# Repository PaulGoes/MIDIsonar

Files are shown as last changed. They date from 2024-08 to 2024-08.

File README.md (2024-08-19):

# MIDIsonar
## An Arduino based MIDI Gesture Controller 
The MIDIsonar is a MIDI Gesture Controller based on an Arduino UNO with two HC-SR04 ultrasonic sensors.

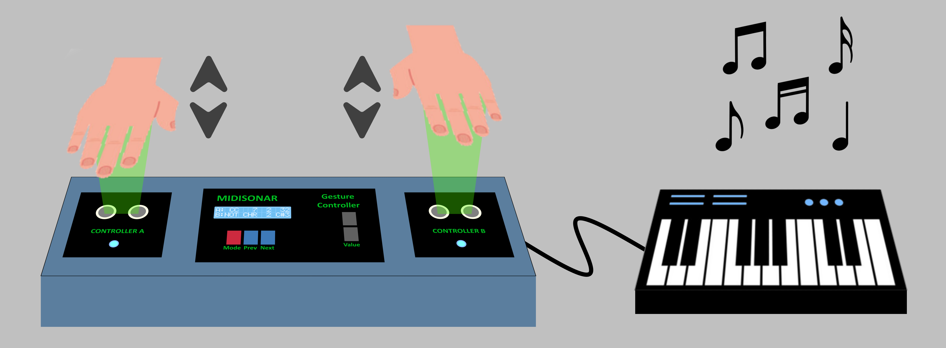
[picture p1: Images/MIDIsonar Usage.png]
MIDIsonar Welcome


With MIDIsonar you have ***two independent sonar based gesture controllers*** that let you create music by waving your hands up and down above the controllers.

Each gesture controller uses a ultrasonic sensor that measures the distance between itself and the hand above it using sonar waves (much like bats do to orientate themselves). 

By varying the distance between your hands and the ultrasonic sensors you ***generate musical information*** that can be send over the MIDI Out to any MIDI capable device like your synthesizer, drum machine or DAW.

<br/>

### MIDI information generated

MIDISonar lets you generate the following MIDI information:
- **MIDI Control Changes - Change the sound characteristics:**
    - Selectable MIDI CC number.
    - Selectable value range (min and max).
- **MIDI Notes - Play melodies and scales:**
    - Selectable root note.
    - Selectable scale (12 different available)
- **MIDI Chords - Play harmonies and progressions:**
    - Selectable root note.
    - Selectable chord progression (9 different available)
- **MIDI Pitchbend - Change the tone height of the sound:**
    - Selectable direction (up, down, up&down).
    - Selectable value range (min and max) and neutral zone .

<br/>

### Controller Configuration

For both controllers the following settings are available:
- **Active status:**
    - Set the controller active or not so you can use both or either one of the controllers.
- **Operational range:**
    - Set the range (minimum and maximum) in cm's in which the controller is operational (from 5cm to 80cm).
- **Polarity:**
    - Set the polarity of the controller, e.g. CC values increase or decrease when your hand is raised.
- **MIDI Channel:**
    - Set the MIDI channel of the controller so you can use both on the same or on different MIDI channels.

<br/>

### Musical usage examples

If set to two different MIDI channels the MIDIsonar can e.g. be used to:
- Play chord progressions with the left hand controlling a pad sound and play note melodies with the right hand controlling a lead sound.
- Control the filter of a running sequence sound with the left hand and play note melodies with the right hand controlling a lead sound.

If set to the same MIDI channel the MIDIsonar can e.g. be used to:
- Control the filter of a sound with the left hand and control the resonance of the same sound with the right hand.
- Control the volume of a sound with the left hand and control the pitch of the same sound to play the sound like a theremin.
- Trigger a single bass drum note with the left hand and trigger another single snare drum note with the right hand to play air drums.

<br/>

## Build it Yourself

You can build the MIDIsonar yourself. Just build it up like shown below and load the MIDIsonar.ino into the Arduino UNO. 

<br/>

### Schematic

Connect the various components as shown in this schematic diagram.

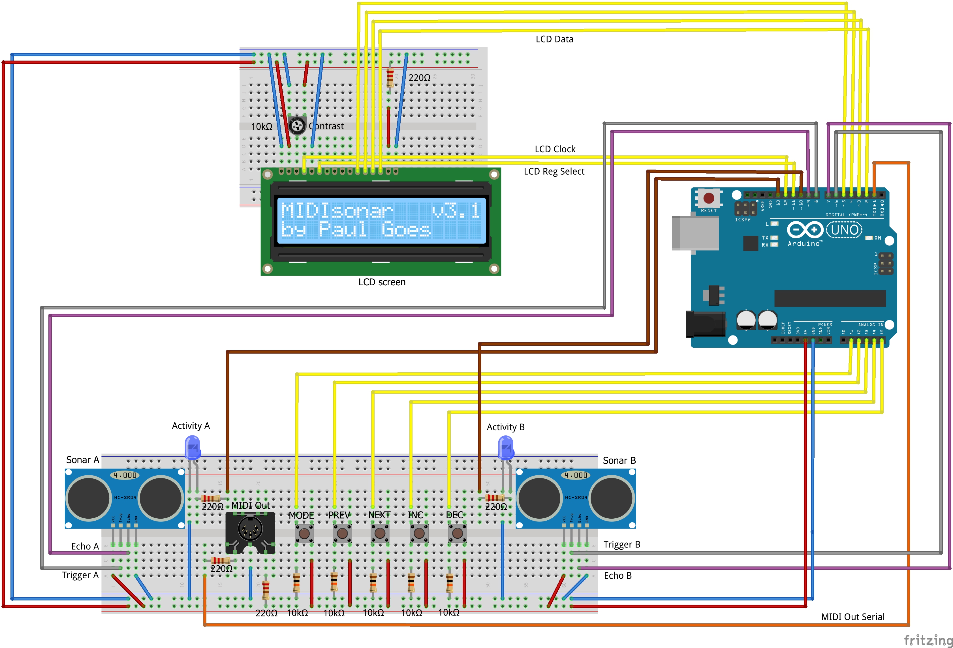
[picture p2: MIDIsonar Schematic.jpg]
MIDIsonar Schematic


<br/>

### Bill Of Materials

To build the MIDIsonar you need the following components.

| Component  | Quantity |
| --- | --- |
| Arduino UNO Microcontroller | 1x  |
| HC-RC04 ULtrasonic sensor  | 2x  |
| HD44780 16x2 LCD screen | 1x |
| MIDI Din Connector | 1x |
| Push buttons | 5x |
| LED diode | 2x |
| Potentiometer 10kOhm | 1x |
| Resistor 220Ohm | 5x |
| Resistor 10kOhm | 5x |
| Breadboard & Wires | 1x |

If you want to build a more permanent solution you might want to solder the components and you additionally need protyping PCB boards and soldering equipment.

If you want to build it into an enclosure you might additionally need wood, paint and screws (wooden enclosure or 3D printing equipment (3D printed plastic enclosure).

<br/>

### GPIO Pin definitions

The MIDIsonar defines the GPIO pins of the Arduino UNO as follows.

| GPIO | Usage | GPIO | Usage |
| --- | --- | --- | --- |
| TXD | Serial MIDI Out | D10 | Activity LED B |
| D2 | LCD Data bit 7 |  D11 | LCD Clock |
| D3 | LCD Data bit 6 | D12 | LCD Register Select |
| D4 | LCD Data bit 5 | D13 | Activity LED A |
| D5 | LCD Data bit 4 | A1 | Button MODE |
| D6 | Sensor B Trigger | A2 | Button PREV |
| D7 | Sensor B Echo | A3 | Button NEXT |
| D8 | Sensor A Trigger | A4 | Button INC |
| D9 | Sensor A Echo | A5 | Button DEC |

In the software the pins are defined at the beginning of the code. If you use another type of Arduino than an Arduino UNO, you might have to change the pin numbers to the corresponding ones for the type that you use.

<br/>

### Software

The software uses the following libraries:
- ``LiquidCrystal.h`` - to interface with the LCD screen
- ``NewPing.h`` - to interface with the ultrasonic sensors

The software consists of a ``setup()`` that initializes the MIDIsonar and displays the welcome message and a ``loop()`` that cycles through the three operational modes Standby, Setup and Play.

The software contains the following functions/subroutines:

- ``MODEstandby()`` - implements the Standby mode
- ``MODEsetup()`` - implements the Setup mode
- ``MODEplay()`` - implements the Play mode
- ``value2string()`` - converts values to strings for displaying purposes
- ``MIDIchord()`` - play chords by decomposing to individual notes
- ``MIDIpitchbend()`` - play pitchbend
- ``MIDImessage()`` - send individual MIDI message

The sketch uses 15010 bytes (46%) of program storage space. Global variables use 1894 bytes (92%) of dynamic memory.

<br/>

### Change the default controller setup

The MIDIsonar uses a default setup for the controllers. This default setup is loaded when the MIDIsonar is turned on. You can change this defaults if you want the MIDIsonar to start up with a different setup.

The default setup for the two controllers is defined at [line 137](https://github.com/PaulGoes/MIDIsonar/blob/b069583abb0d174fe831ef4dbfc4291921db8744/MIDIsonar.ino#L137) of the code.

```
/* initialize the data array with default values */
int value[2][18] = {
  { 1, 1, 1, 5, 50, 1, 7, 0, 127, 1, 60, 24, 1, 60, 14, 3, 3, 1 },	/* controller A: Active | CC 7 Volume over full range 0-127               */
  { 1, 2, 1, 5, 50, 1, 7, 0, 127, 1, 60, 24, 1, 60, 14, 3, 3, 1 }  	/* controller B: Active | NOTE Chromatic scale with root C3 with 24 steps */
```

The settings map to the following: 
| Controller| ACTV | TYPE | CHNL | LDST | HDST | POLR | CNTR | LVAL | HVAL | SCAL | ROOT | RANG | PROG | ROOT | RANG | TYPE | NTRL | PBFX |
| --- | --- | --- | --- | --- | --- | --- | --- | --- | --- | --- | --- | --- | --- | --- | --- | --- | --- | --- |
|  |  |  |  |  |  |  | CC | CC | CC | NOT | NOT | NOT | CHD | CHD | CHD | PB | PB | PB |
| A | 1 | 1 | 1 | 5 | 50 | 1 | 7 | 0 | 127 | 1 | 60 | 24 | 1 | 60 | 14 | 3 | 3 | 1 |
| B | 1 | 2 | 1 | 5 | 50 | 1 | 7 | 0 | 127 | 1 | 60 | 24 | 1 | 60 | 14 | 3 | 3 | 1 |

The defaults of both controllers are basically the same:

- Both send on MIDI channel 1 (CHNL) with a working range from 5 cm (LDST) to 50 cm (HDST).
- Controller A is set to TYPE 1 which means to send MIDI CC information. So it uses the config for the CC information: sending CC 7 (CC CNTR) over the full range of 0 (CC LVAL) to 127 (CC HVAL).
- Controller B is set to type 2 which means to send MIDI NOTE information. So it uses the config for the NOT information: using the chromatic scale (NOT SCAL) with root note C3 (NOT ROOT) and a range of 24 notes (NOT RANG).

The file [MIDIsonar datastructure pdf](https://github.com/PaulGoes/MIDIsonar/blob/master/MIDIsonar%20Datastructure.pdf) defines the settings and the values that can be used.

<br/>

### Change the controller sensitivity

The MIDIsonar's sensitivity can be changed in two different ways: configuring the ping medians and configuring the wiggle room.

The ping medians are defined at [line 149](https://github.com/PaulGoes/MIDIsonar/blob/b069583abb0d174fe831ef4dbfc4291921db8744/MIDIsonar.ino#L149) of the code.

```
/* initialize the data array with ping medians */
int pingmedian[4] = { 2, 3, 3, 2 };
```

The ultrasonic sensors work by sending a ping and measuring the time until they receive the echo. In order to prevent rogue measurements, it is possible to send multiple pings, discard the out-of-range measurements and calculate an average. The pingmedian array defines how many pings are used for each type of operation: MIDI CC (2), MIDI Notes (3), MIDI Chords (3), and MIDI Pitchbend (2).

> [!NOTE]
> Increasing the number of pings makes the measurements more reliable, but also makes the MIDIsonar react slower to the hand movements. So changing the ping medians is an act of balancing reliability vs performance.

The wiggle rooms are defined at [line 152](https://github.com/PaulGoes/MIDIsonar/blob/b069583abb0d174fe831ef4dbfc4291921db8744/MIDIsonar.ino#L152) of the code. 

```
/* initalize the data array with wiggle room */
int wiggleroom[4] = { 10, 10, 10, 0 };
```

The wiggle room is the minimum amount that a new measurement must differ from the previous measurement in order to be processed (in microseconds). This prevents that small movements of the hand or small imperfections in the measurements result in false triggerings. The wiggleroom array defines the wiggle rooms that are used for each type of operations: MIDI CC (10), MIDI Notes (10), MIDI Chords (10), and MIDI Pitchbend (0).

> [!NOTE]
> Increasing the wiggle room prevents false triggerings, but also makes the MIDIsonar react less well to small hand movements. So changing the wiggle room is an act of balancing accuracy vs coarseness.

<br/>

## Photo's

Here are some photo's of my MIDIsonar to give you inspiration to design you own enclosure.

MIDIsonar Photos

<br/>

## User Manual

When you power on the MIDIsonar it starts up with the welcome screen that displays the software version.

MIDIsonar Welcome

After a few seconds the MIDIsonar switches to the Standby Mode.

MIDIsonar Standby

<br/>

### Select Modes

By pressing the :red_square:**MODE** button you can cycle trought the three modes Standby, Setup and Play.

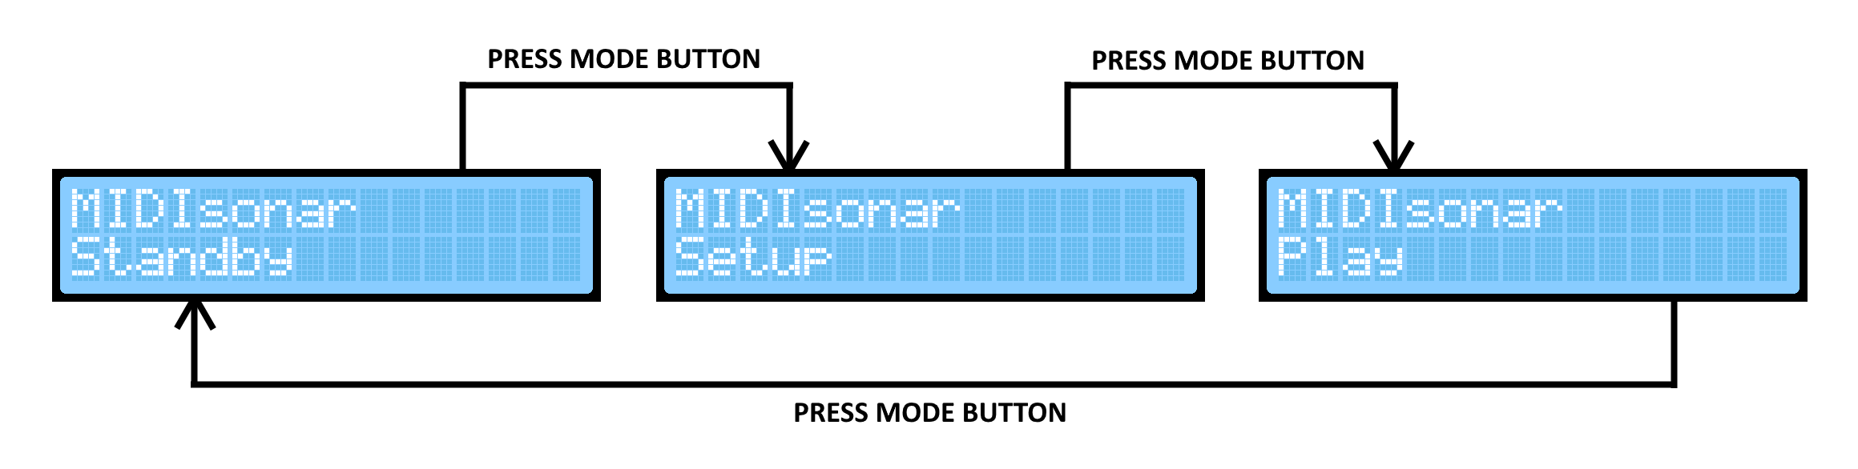
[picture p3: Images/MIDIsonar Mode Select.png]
MIDIsonar Mode Select


<br/>

### Play Mode

The MIDIsonar has a default setup and you can immediately use it by going to the Play mode. The default setup is:

MIDI controller A: 
- Active with a range from 5cm to 50cm, positive polarity.
- MIDI channel 1.
- Sending MIDI CC 7 (Volume) over the full range of 0 to 127.
  
MIDI controller B: 
- Active with a range from 5cm to 50cm, positive polarity.
- MIDI channel 1.
- Sending MIDI NOTES using a chromatic scale with root note C3 divided in 24 steps.

> [!NOTE]
> When in Play mode the activity LED's for controller A and controller B indicate whether the controller is active (lit) or not (dimmed).

When in Play mode the LCD screen gives visual feedback on the controls. For the default setup it shows the following information.

MIDIsonar Play Default

You can read from this screen that controller A is now sending CC 7 with a value 32 on MIDI channel 1 and controller B is now sending note G#3 also on MIDI channel 1.

<br/>

### Setup Mode

In Setup mode you can configure the settings for both controllers.

When you go into Setup Mode for the first time you are presented the first setup screen for controller A.

MIDIsonar Setup 1

The cursor (a thin line at the bottom) indicates which setting is currently selected. 

You can select different settings by pressing the :blue_square:**PREV** button (previous) and :blue_square:**NEXT** button (next). By pressing these buttons you cycle through the settings of controller A and controller B.

> [!NOTE]
> When you press the :blue_square:**NEXT** button at the last setting of controller B you will go to the first setting of controller A.<br/>
>
> When you press the :blue_square:**PREV** button at the first setting of controller A you will go to the last setting of controller B.

You can change the value of the selected setting by pressing the :black_large_square:**DEC** button (decrease) and :black_large_square:**INC** button (increase). 

> [!TIP]
> If you keep either :black_large_square:**DEC** or :black_large_square:**INC** button pressed it will scroll faster through the values.

> [!NOTE]
> When you return to Setup Mode after visiting Play mode you will return to the most recently edited setting.

<br/>

### Setup Screen organization

Each controller is configured by 9 settings arranged in 3 screens of 3 settings each. The third screen has settings that are dependent of the chosen type of operation on screen 1.

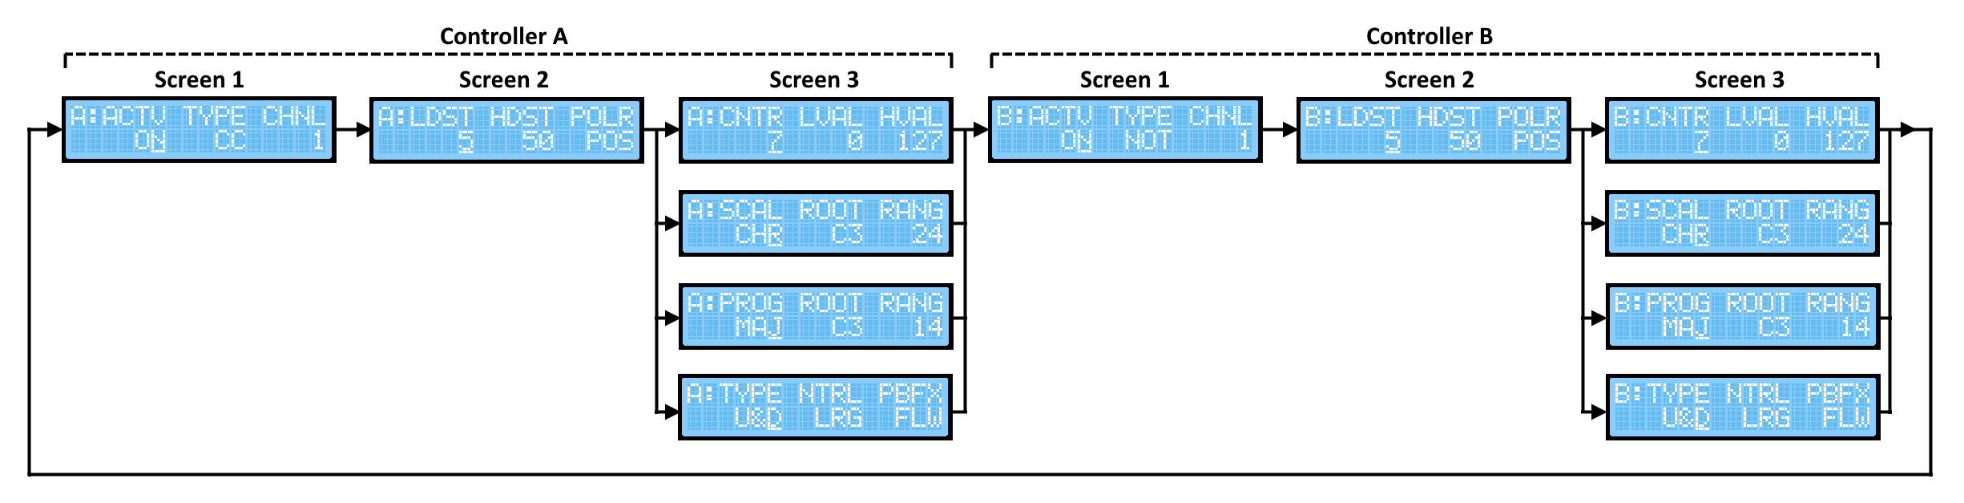
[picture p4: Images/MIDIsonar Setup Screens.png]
MIDIsonar Setup Organization


<br/>

### Settings of the first Setup screen

MIDIsonar Setup 1

- **ACTV:** Active
  - ON = Active
  - OFF = Inactive
- **TYPE:** Type of operation
  - CC = Send MIDI CC changes
  - NOT = Send MIDI Notes
  - CHD = Send MIDI Chords
  - PB = Send MIDI Pitchbend
- **CHNL:** MIDI Channel
  - 1-16 = MIDI Channel number

<br/>

### Settings of the second Setup screen

MIDIsonar Setup 2

- **LDST:** Low Distance
  - 5-80 = Low end of the operating range in cm (in steps of 5)
- **HDST:** High Distance
  - 5-80 = High end of the operating range in cm (in steps of 5)
- **POLR:** Polarity
  - POS = Positive mapping
  - NEG = Negative mapping
    
> [!NOTE]
> The HDST must be higher than the LDST. This is enforced when setting the values. 

The following image illustrates the effect of using positive and negative polarity.

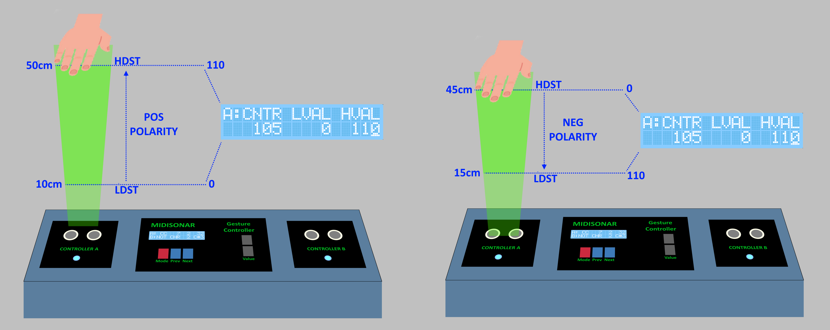
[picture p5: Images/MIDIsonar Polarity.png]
MIDIsonar Polarity


<br/>

### Settings of the third Setup screen - MIDI CC Changes

MIDIsonar Setup 3 CC

- **CNTR:** Controller number
  - 0-127 = MIDI CC number
- **LVAL:** Low Value
  - 0-127 = Lowest value generated
- **HVAL:** High Value
  - 0-127 = Highest value generated

> [!NOTE]
> The HVAL must be higher than the LVAL. This is enforced when setting the values. 

> [!TIP]
> The use of MIDI CC is synthesizer specific. So the manufacturer of the synthesizer determines which CC value controls what parameter of the sound engine. So take a look at the manual of the synthesizer for a mapping of the CC values. Most likely there will be an appendix with a name of MIDI controller list (or equivalent).

The following image illustrates controlling the filter cutoff (controller A) and filter resonance (controller B) on a Novation KS-rack synthesizer module. 

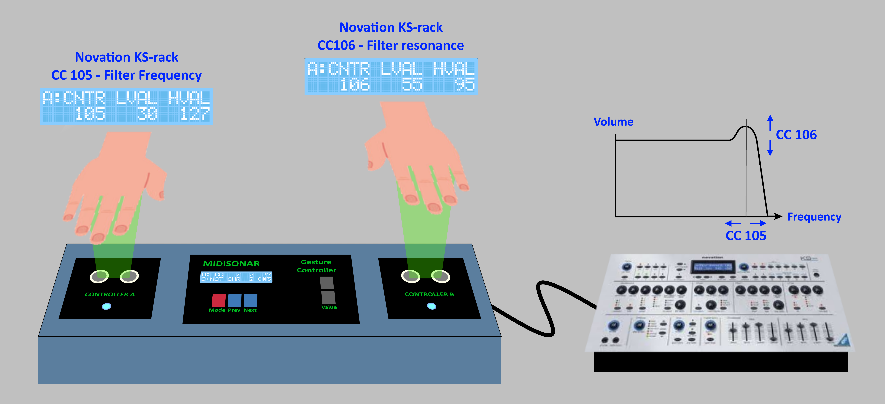
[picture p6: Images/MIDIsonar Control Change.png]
MIDIsonar Control Chnage


<br/>

### Settings of the third Setup screen - MIDI Notes

MIDIsonar Setup 3 NOT

- **SCAL:** Musicial note scale
  - CHR = Chromatic scale
  - MAJ = Major scale
  - MIN = Minor scale
  - MMI = Melodic Minor scale
  - HMI = Harmonic Minor scale
  - WHL = Whole Tone scale
  - MAB = Major Blues scale
  - MIB = Minor Blues scale
  - MA5 = Major Pentatonic scale
  - MI5 = Minor Pentatonic scale
  - 8WH = Octatonic Whole Half scale
  - 8HW = Octatonic Half Whole scale
- **ROOT:** Root note
  -  C0-B8 - Root note for the scale
-  **RANG:** Number of scale notes to be played

The following image shows the notes of the different scales for the root note C.

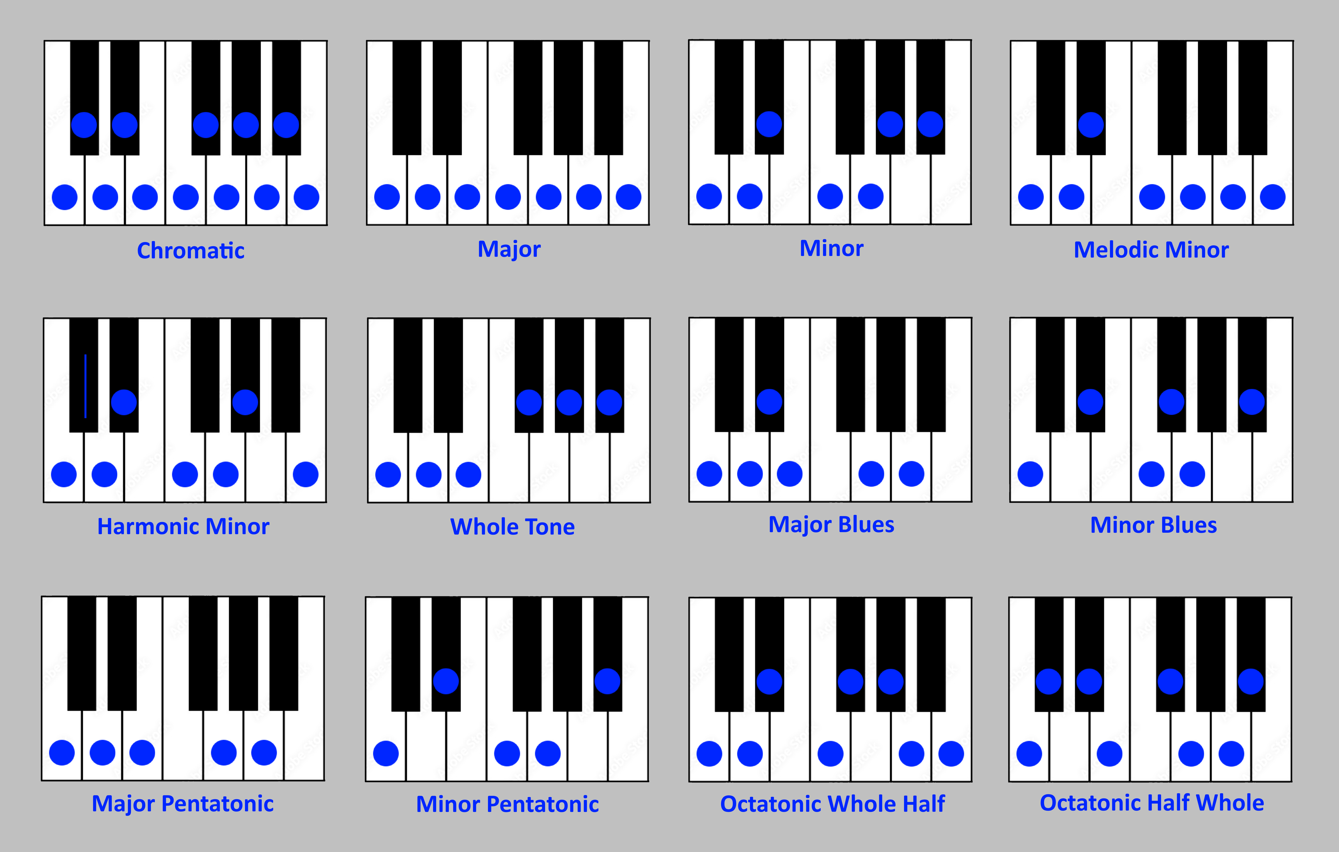
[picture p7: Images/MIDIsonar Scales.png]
MIDISonar Scales


<br/>

### Settings of the third Setup screen - MIDI Chords

MIDIsonar Setup 3 CHD

- **PROG:** Musical chord progression
  - MAJ = Major chord progression
  - MIN = Minor chord progression
  - MAB = Major Blues 7th chord progession
  - MIB = Minor Blues 7th chord progression
  - POP = Pop chord progression
  - JAZ = Jazz chord progression (undocumented)
  - MOD = Modal chord progression (undocumented)
  - GSP = Gospel chord progression (undocumented)
  - PBL = Pachelbel chord progression (undocumented)
- **ROOT:** Root note
  - C0-B8 - Root note for the chord progression
- **RANG:** Number of progression chords to be played 

The following image shows the chords of the different progressions for the root note C.

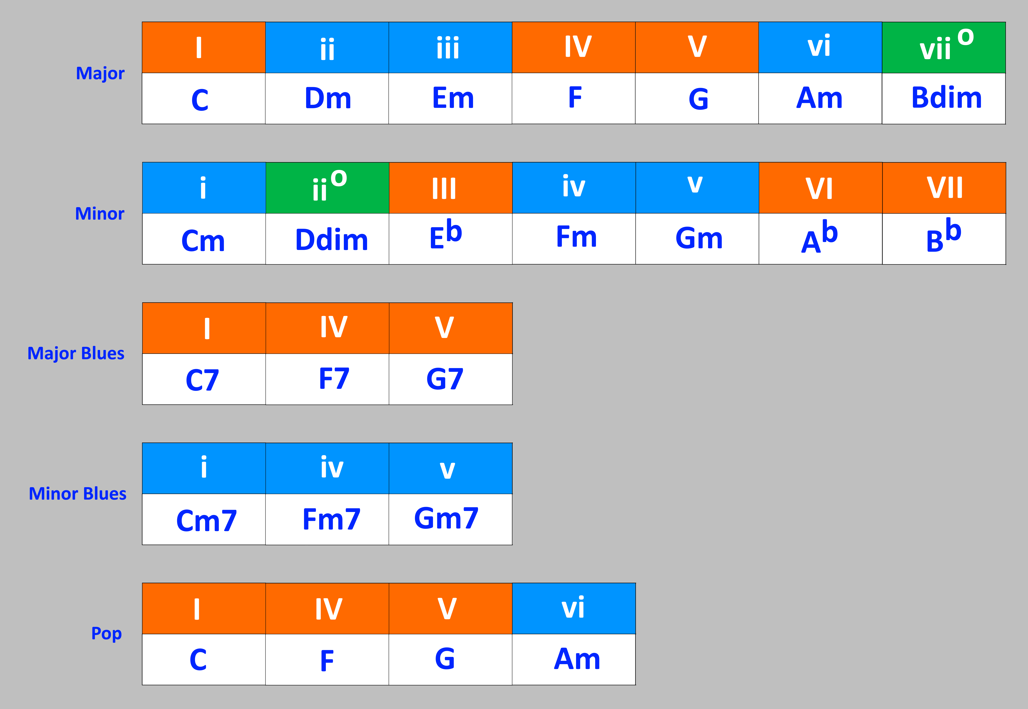
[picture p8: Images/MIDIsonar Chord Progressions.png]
MIDIsonar Progressions


<br/>

### Settings of the third Setup screen - MIDI Pitchbend

MIDIsonar Setup 3 PB

- **TYPE:** Pitchbend type
  - UP = Bend the pitch up
  - DWN = Bend the pitch down
  - U&D = Bend the pitch up and down  
- **NTRL:** Neutral zone size
  - SML = Small
  - MED = Medium
  - LRG = Large
- **PBFX:** Pitchbend effects
  - FLW = Flowing pitch bend
  - STP = Stepping pitch bend  

The following image shows the effect of using the pitchbend types and neutral zone sizes.

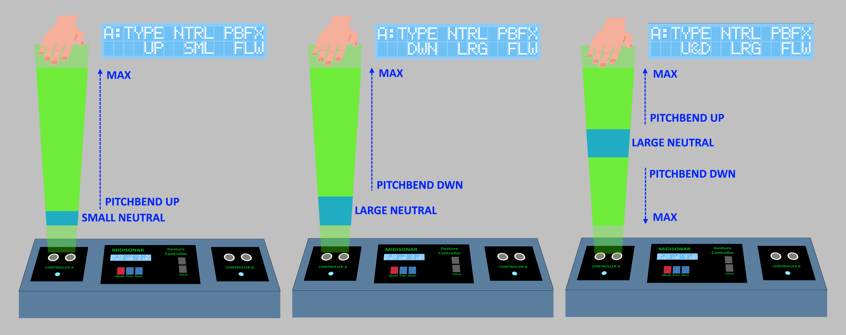
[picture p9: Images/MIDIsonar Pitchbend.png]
MIDIsonar Pitchbend


> [!NOTE]
> The neutral zone is comparable to a pitchbend wheel in its neutral/center position. The pitchbend maximum is comparable to a pitchbend wheel completely up or down. As with the pitchbend wheel this doesn't say anything about the actual pitchbend in semitones. The semitone range of the pitchbend is determined by the setup of the synthesizer. On most synthesizers it is even possible to setup individual semitone ranges for pitchbend up and pitchbend down.

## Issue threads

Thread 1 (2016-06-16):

Bug: LDST and HDST displays wrong values when LDST>HDST and HDST<LDST

PaulGoes, 2016-06-16:
The LDST and HDST values are interdependent. LDST must be a lower value than HDST. LDST and HDST must be in the range between 5 cm and 80 cm and can be adjusted in 5 cm increments. When you try to make LDST greater than HDST that is blocked, but at a wrong value. If e.g. the HDST is 50 and the LDST is incremented from 45 to 50 the LDST is adjusted to 49. This must be 45.

PaulGoes, 2016-06-18:
Solved in version 0.6.

Closed 2016-06-18.

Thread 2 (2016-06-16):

Bug: Jitter at certain positions of the value dial

PaulGoes, 2016-06-16:
When trying to set a value in the menu it displays jitter: the value switches fast between two adjacent values. This is probably caused by the potentiometer being in a position between values that gives alternating values when reading it with analogRead().

PaulGoes, 2016-06-18:
Solved in version 0.6.

Closed 2016-06-18.

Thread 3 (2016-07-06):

Bug: Alternating adjacent notes when playing notes

PaulGoes, 2016-07-06:
When the controller is set to Type NOT, playing notes results in alternating notes when your hand is at a position exactly between two adjacent notes. This is problably caused because the hand is not a perfectly flat surface and the sensor jitters in a small range (and playing the adjacent notes alternately). When a flat surface is used to control the sensor (for example a book) the problem is nonexistent. This must be solved because we want to control the sensor by waving hands.

PaulGoes, 2016-07-14:
Solved in version 0.8.

Closed 2016-07-14.

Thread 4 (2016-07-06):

Bug: No NoteOff Midi message sent when hand is out of range

PaulGoes, 2016-07-06:
When the controller is set to Type NOT, playing notes results in continuously sounding notes when the hand is out of range. When in Type NOT the controller should send a midi NoteOff message when the readings are out of range. This is not the case. The NoteOff Message is only send when the hand is in range again.

PaulGoes, 2016-07-14:
Solved in version 0.8.

Closed 2016-07-14.

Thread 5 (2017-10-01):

Stuck at “Standby Mode”

numinosum, 2017-10-01:
Hello,
I got very enthousiastic about the MidiSonar and attempted to replicate it. Unfortunately I got stuck at the Standby Mode screen. The buttons are not responding, only one of the LEDs is flashing at startup. I am using an Arduino Leonardo and TeenOnArdu id. Could you please let me know where I might have been wrong?
Another thing: one potentiometer is for the brightness of the lcd but what does the other one do?
Thanks a lot and thanks for uploading your work!
Regards,
Malen

PaulGoes, 2017-10-02:
Hi Malen,

Nice to hear that someone is trying to build it too.

When I switch the MidiSonar on, it displays the text 'MIDIsonar   v0.9' on the first line of the LCD and then flashes the text 'by Paul Goes' three times on  the second line of the LCD.

After that it automatically goes to the Standby mode and displays the text 'MIDIsonar' on the first line of the LCD and the text 'Standby' on the second line of the LCD.

Then by pressing the buttonpin1 (=Analog A1 on pin nr 15) you can loop through the tree modes:
'Standby' --> 'Setup' --> 'Play' (and back again to Standy.

In Setup mode you can use the buttons buttonpin2 (=Analog A2 on pin 16) to go to the previous menu-item and buttonpin3 (=Analog A3 on pin 17) to go to the next menu-item. The currently selected menu-item is indicated by the underscore. When a menu-item is selected you can change the value of it by rotating the potentiometer (thats what that potentiometer is for: changing the values).

Hope that this helps.

numinosum, 2017-10-03:
Hi again,

Thanks so much for your reply! It does help me to understand the structure and the sonar loads just as you described (so the setup and the screen work up to that point), however I still cannot get past the Standby Mode. The buttons simply do not respond. So I am wondering where I might be wrong. Do you think the Arduino version matters? I have a Leonardo as a TeeOnArdu board which makes it a class compliant usb-midi device. Tried setting it as a regular Leonardo too but it is all the same. I checked all my connections, still nothing. As I mentioned, only one of my LEDs flashes after reset. Where do you think I should look?

Can you confirm the specs of your components? I use 10kOhm pots and 10kOhm (brown, black, orange, gold) and 220 Ohm (red, red, brown, gold) resistors. Is the second pot actually an encoder?

I am new to Arduino as you can see so sorry if my questions sound a bit naive. Any help is much appreciated.
Best wishes,
Malen

PaulGoes, 2017-10-04:
Hi Malen,

I've only used the Arduino Uno and never the Leonardo. What I see from various sites on the Internet, is that the Leonardo works a little different when using analog pins as digital pins. That is what MidiSonar does: the three digital buttons use analog pins: 'Button MODE SELECT' = A1, 'Button MENU PREV' = A2 and 'Button MENU NEXT' = A3.

On the Arduino UNO this maps as: A1 = pin 15, A2 = pin 16 and A3 = pin 17.

But on the Arduino Leonardo this maps as: A1 = pin 19, A2 = pin 20 and A3 = pin 21 (if I interpret the information on Internet correctly).

This might cause your problems. It is using the wrong pin definitions. What you could try is to change the mapping of buttonPin1, buttonPin2 and buttonPin3 in the '/* initialize the push buttons */' section of the code to 19, 20 and 21 respectively.

Both pots are simple potentiometers and not rotary encoders. An endless rotary encoder for data entry would be more intuitive to use, but requires changes in the code. Maybe I will do that later, but for know a simple potentiometer works also.

Hope this helps!

numinosum, 2017-10-05:
Brilliant!! It worked!

Just as you presumed, the pin definitions needed to be changed to 19, 20 and 21 and it is now fully functional. Thank you so much!!

I still have to figure out how to make it work as a usb midi device so I am digging into code and libraries. If I manage I could upload my version here. But so far my problem is solved and I am verry grateful :)

Best wishes,
Malen

numinosum, 2017-10-05:
PS: I am interested in developing this project and perhaps adding additional features like cc controls or keys or even sensors to it. Please get in touch if you are too. My mail is actinplay@gmail.com . Best, Malen

Closed 2017-10-05.

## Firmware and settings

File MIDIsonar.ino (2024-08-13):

/* MIDIsonar                                                                    */
/* ---------------------------------------------------------------------------- */
/* Author:  Paul Goes                                                           */
/* Version: 3.1                                                                 */
/* Date:    19-03-2024                                                          */
/* ---------------------------------------------------------------------------- */ 
/* Revision history:                                                            */
/*                                                                              */
/* v0.1    : Initial version. Only contains simple LCD functionality that       */
/*           enables to scroll through the different modes: STANDBY, SETUP and  */
/*           PLAY.                                                              */
/*                                                                              */
/* v0.2    : Added data array that holds the setup values. Initialized the      */
/*           data array with the default values. Implemented temporary PLAY     */
/*           mode functionality that shows the contents of the array on the     */
/*           LCD display.                                                       */
/*                                                                              */
/* v0.3    : Added function that converts integer value to string in order to   */
/*           display meaningful values on the LCD.                              */
/*                                                                              */
/* v0.4    : Added setup mode. Navigation through the six setup screens. Setup  */
/*           screens display the initalizaton data from the data array.         */
/*           Changing the data values is not yet implemented.                   */
/*                                                                              */
/* v0.5    : Added the functionality to change values in setup mode.  Added     */
/*           extensive in-code comments to document the logic.                  */
/*                                                                              */
/* v0.6    : Solved bug #1 'LDST and HDST displays wrong values when LDST>HDST  */
/*           and HDST<LDST' and solved bug #2 'Jitter at certain positions of   */
/*           the value dial'.                                                   */
/*                                                                              */
/* v0.7    : Implemented play mode. Implemented is only sonar controller A.     */
/*           For this controller the complete functionality is implemented.     */
/*           Both controller types (MIDI notes and MIDI CC) are implemented.    */
/*                                                                              */
/* v0.8    : Solved bug #3 'Alternating adjacent notes when playing notes' and  */
/*           solved bug 'No NoteOff Midi message sent when hand is out of       */
/*           range'.                                                            */
/*                                                                              */
/* v0.9    : Implemented play mode for sonar controller B.                      */
/*                                                                              */
/* v1.0    : Implemented setting values by two new buttons for INC and DEC.     */
/*           The value potentiometer is removed and no longer functional.       */
/*                                                                              */
/* v1.1    : Switched pins for sonar controller A and sonar controller B to     */
/*           fix the build error in which the controllers are build into the    */
/*           wrong physical slots.                                              */ 	
/*                                                                              */
/* v2.0    : Changed implementation of the MIDI notes functionality. It is now  */
/*           possible to select a scale to use when playing the notes. The      */
/*           scale is played starting from a specified root note which          */
/*           determines the key that the scale is played in.                    */
/*                                                                              */
/* v2.1    : Added implementation of the MIDI chords functionality. It is now   */
/*           possible to select a progression to use when playing the chords.   */
/*           The progression is played starting from a specified root note      */
/*           which determines the key the progression is played in.             */
/*                                                                              */
/* v2.2    : Added implementation of additional MIDI chord progressions.        */
/*                                                                              */
/* v2.3    : Added implementation of the MIDI pitchbend functionality. It is    */
/*           possible to select a whether bending up only, bending down only    */
/*           or bending up and down. In all three settings there is a neutral   */
/*           zone of configurable size that corresponds to the central pitch.   */
/*                                                                              */
/* v2.4    : Enhanced menu handling. When returning to setup it returns to the  */
/*           previously selected menu item. When selecting NEXT at the last     */
/*           menu item it selects the first menu item and when selecting PREV   */
/*           at the first menu item it selects the last menu item.              */ 
/*                                                                              */
/* v2.5    : Solved issue with the MIDI chord progressions. The new chord was   */
/*           played with the wrong chord type and the note off was played with  */
/*           the correct chord type resulting in notes sustaining.              */
/*                                                                              */
/* v3.0    : Added MIDI reset when leaving play mode. Notes that are sounding   */
/*           are released and the pitch bend is reset to neutral position.      */
/*                                                                              */
/* v3.1    : Enhanced playing of note scales and chord progressions. In         */
/*           previous versions it played one note/chord outside of the range.   */
/*           With a range of 1 it played 2 notes/chords, with the range set     */
/*           to maximum it tried to play a note outside of the arrays.          */
/*           With range of a single note it is now possible to trigger single   */
/*           notes/chords with more precision.                                  */
/* ---------------------------------------------------------------------------- */

/* ---------------------------------------------------------------------------- */
/* Arduino Pin connections:                                                     */
/*    TXD - MIDI OUT Serial               D10 - Sonar B Led                     */
/*    D2  - LCD Bit 7 (pin 14)            D11 - LCD Clock (pin 6)               */
/*    D3  - LCD Bit 6 (pin 13)            D12 - LCD Reg Select (pin 4)          */    
/*    D4  - LCD Bit 5 (pin 12)            D13 - Sonar A Led                     */
/*    D5  - LCD Bit 4 (pin 11)            A0  - Potmeter Value (deprecated)     */
/*    D8  - Sonar A Trigger               A1  - Button MODE SELECT              */
/*    D9  - Sonar A Echo                  A2  - Button MENU PREV                */
/*    D6  - Sonar B Trigger               A3  - Button MENU NEXT                */
/*    D7  - Sonar B Echo                  A4  - Button VALUE INC                */
/*                                        A5  - Button VALUE DEC                */
/* ---------------------------------------------------------------------------- */


/* include the library code */
#include <LiquidCrystal.h>
#include <NewPing.h>

/* initialize the library with the numbers of the interface pins */
LiquidCrystal lcd(12, 11, 5, 4, 3, 2);

/* initialize the push buttons */
const int buttonPin1 = 15;   /* button 1 connected to pin 15 (analog A1) MODE SELECT */
const int buttonPin2 = 16;   /* button 2 connected to pin 16 (analog A2) MENU PREV   */
const int buttonPin3 = 17;   /* button 3 connected to pin 17 (analog A3) MENU NEXT   */
const int buttonPin4 = 18;   /* button 4 connected to pin 18 (analog A4) VALUE INC   */
const int buttonPin5 = 19;   /* button 5 connected to pin 19 (analog A5) VALUE DEC   */

/* initialize the LEDs */
const int ledPinA = 13;      /* activity LED used for controller A connected to pin D13 */
const int ledPinB = 10;      /* activity LED used for controller B connected to pin D10 */

/* initialize the potentiometer */
const int potPin1 = 0;       /* potentiometer 1 connected to pin 1 (analog A0) VALUE */

int buttonState = 0;

/* initialize the start menu position */
int menu_id = 0;        /* menu id of the selected menu item */
int menu_id_old = 3;    /* menu id of the previous menu item */

/* initialize the Sonars */
#define triggerPinA   8      /* trigger pin sonar sensor A connected to pin D8 */
#define echoPinA      9      /* echo pin sonar sensor A connected to pin D9    */
#define triggerPinB   6      /* trigger pin sonar sensor B connected to pin D6 */
#define echoPinB      7      /* echo pin sonar sensor B connected to pin D7    */

NewPing sonarA(triggerPinA, echoPinA, 100);   /* NewPing setup of sonar A pins and maximum distance */
NewPing sonarB(triggerPinB, echoPinB, 100);   /* NewPing setup of sonar A pins and maximum distance */

/* initialize the data array with default values */
int value[2][18] = {
  { 1, 1, 1, 5, 50, 1, 7, 0, 127, 1, 60, 24, 1, 60, 14, 3, 3, 1 },	/* controller A: Active | CC 7 Volume over full range 0-127               */
  { 1, 2, 1, 5, 50, 1, 7, 0, 127, 1, 60, 24, 1, 60, 14, 3, 3, 1 }  	/* controller B: Active | NOTE Chromatic scale with root C3 with 24 steps */
};

/* initialize the data array with valuetypes */
int type[18] = { 2, 3, 1, 1, 1, 4, 1, 1, 1, 5, 6, 1, 7, 6, 1, 8, 9, 10 };

/* initialize the string array with menu names */
char* menu[] = { "ACTV", "TYPE", "CHNL", "LDST", "HDST", "POLR", "CNTR", "LVAL", "HVAL", "SCAL", "ROOT", "RANG", "PROG", "ROOT", "RANG", "TYPE", "NTRL", "PBFX" };

/* initialize the data array with ping medians */
int pingmedian[4] = { 2, 3, 3, 2 };

/* initalize the data array with wiggle room */
int wiggleroom[4] = { 10, 10, 10, 0 };

/* initialize the data array with scales */
int scales[12][24] = {
  {  0,  1,  2,  3,  4,  5,  6,  7,  8,  9, 10, 11, 12, 13, 14, 15, 16, 17, 18, 19, 20, 21, 22, 23 },   /* Chromatic            */
  {  0,  2,  4,  5,  7,  9, 11, 12, 14, 16, 17, 19, 21, 23, 24, 26, 28, 29, 31, 33, 35, 36, 38, 40 },   /* Major                */
  {  0,  2,  3,  5,  7,  8, 10, 12, 14, 15, 17, 19, 20, 22, 24, 26, 27, 29, 31, 32, 34, 36, 38, 39 },   /* Minor                */
  {  0,  2,  3,  5,  7,  9, 11, 12, 14, 15, 17, 19, 21, 23, 24, 26, 27, 29, 31, 33, 35, 36, 38, 39 },   /* Melodic Minor        */
  {  0,  2,  3,  5,  7,  8, 11, 12, 14, 15, 17, 19, 20, 23, 24, 26, 27, 29, 31, 32, 35, 36, 38, 39 },   /* Harmonic Minor       */
  {  0,  2,  4,  6,  8, 10, 12, 14, 16, 18, 20, 22, 24, 26, 28, 30, 32, 34, 36, 38, 40, 42, 44, 46 },   /* Whole Tone           */
  {  0,  2,  3,  4,  7,  9, 12, 14, 15, 16, 19, 21, 24, 26, 27, 28, 31, 33, 36, 38, 39, 40, 43, 45 },   /* Major Blues          */
  {  0,  3,  5,  6,  7, 10, 12, 15, 17, 18, 19, 22, 24, 27, 29, 30, 31, 34, 36, 39, 41, 42, 43, 46 },   /* Minor Blues          */
  {  0,  2,  4,  7,  9, 12, 14, 16, 19, 21, 24, 26, 28, 31, 33, 36, 38, 40, 43, 45, 48, 50, 52, 55 },   /* Major Pentatonic     */ 
  {  0,  3,  5,  7, 10, 12, 15, 17, 19, 22, 24, 27, 29, 31, 34, 36, 39, 41, 43, 46, 48, 51, 53, 55 },   /* Minor Pentatonic     */
  {  0,  2,  3,  5,  6,  8,  9, 11, 12, 14, 15, 17, 18, 20, 21, 23, 24, 26, 27, 29, 30, 32, 33, 35 },   /* Octatonic Whole Half */
  {  0,  1,  3,  4,  6,  7,  9, 10, 12, 13, 15, 16, 18, 19, 21, 22, 24, 25, 27, 28, 30, 31, 33, 34 }    /* Octatonic Half Whole */
};

/* initialize the data array with progressions */
int progs[9][14][2] = {
  { {0,2} , {2,3} , {4,3} , {5,2} , {7,2} , {9,3} , {11,5} , {12,2} , {14,3} , {16,3} , {17,2} , {19,2} , {21,3} , {23,5} },                    /* Major           */
  { {0,3} , {2,5} , {3,2} , {5,3} , {7,3} , {8,2} , {10,2} , {12,3} , {14,5} , {15,2} , {17,3} , {19,3} , {20,2} , {22,2} },                    /* Minor           */
  { {0,8} , {5,8} , {7,8} , {12,8} , {17,8} , {19,8} , {24,8} , {29,8} , {31,8} , {36,8} , {41,8} , {43,8} , {48,8} , {53,8} },                 /* Major Blues 7th */
  { {0,10} , {5,10} , {7,10} , {12,10} , {17,10} , {19,10} , {24,10} , {29,10} , {31,10} , {36,10} , {41,10} , {43,10} , {48,10} , {53,10} } ,  /* Minor Blues 7th */
  { {0,2} , {5,2} , {7,2} , {9,3} , {12,2} , {17,2} , {19,2} , {21,3} , {24,2} , {29,2} , {31,2} , {33,3} , {36,2} , {41,2} } ,                 /* Pop             */
  { {0,9} , {2,10} , {7,8} , {12,9} , {14,10} , {19,8} , {24,9} , {26,10} , {31,8} , {36,9} , {38,10} , {43,8} , {48,9} , {50,10} } ,           /* Jazz            */
  { {0,2} , {5,2} , {10,2} , {12,2} , {17,2} , {22,2} , {24,2} , {29,2} , {34,2} , {36,2} , {41,2} , {46,2} , {48,2} , {53,2} } ,               /* Modal           */
  { {0,2} , {2,3} , {4,3} , {5,2} , {7,2} , {9,3} , {11,5} , {12,2} , {14,3} , {16,3} , {17,2} , {19,2} , {21,3} , {23,5} } ,                   /* Gospel          */
  { {0,2} , {4,3} , {5,3} , {7,3} , {9,2} , {12,2} , {16,3} , {17,3} , {19,3} , {21,2} , {24,2} , {28,3} , {29,3} , {31,3} }                    /* Pachelbel       */
};

/* ---------------------------------------------------------------------------- */
/* Setup portion of the Arduino program.                                        */
/* ---------------------------------------------------------------------------- */

void setup() 
{
  /* initialize serial MIDI OUT interface with the correct baud rate */
  Serial.begin(31250);
  
  /* set up the LCD's number of columns and rows */
  pinMode(buttonPin1, INPUT);
  pinMode(buttonPin2, INPUT);
  pinMode(buttonPin3, INPUT);
  pinMode(ledPinA, OUTPUT);
  pinMode(ledPinB, OUTPUT);
  
  /* set up the LCD screen as 2 lines of 16 characters */
  lcd.begin(16, 2);

  /* clear the LCD display */
  lcd.clear();

  /* display productname and version */
  lcd.setCursor(0, 0);
  lcd.print("MIDIsonar   v3.1");

  delay(1000);

  /* display the welcome message */
  for(int counter=0; counter<3; counter++)
  {
      lcd.setCursor(0,1); lcd.print("by Paul Goes");
      delay(750);

      lcd.setCursor(0,1); lcd.print("            ");
      delay(750);
  }

  lcd.clear();

}


/* ---------------------------------------------------------------------------- */
/* Loop portion of the Arduino program.                                         */
/* ---------------------------------------------------------------------------- */

void loop() 
{
    /* cycle through the three modes */
    MODEstandby();     
    MODEsetup();      
    MODEplay();       
}


/* ---------------------------------------------------------------------------- */
/* MODEstandby():                                                               */
/* Function:     Implements the standby mode.                                   */
/* Arguments:    None.                                                          */
/* ---------------------------------------------------------------------------- */
void MODEstandby()
{
  /* display the mode message */
  lcd.clear();
  lcd.setCursor(0,0); lcd.print("MIDIsonar");
  lcd.setCursor(0,1); lcd.print("Standby");
  delay(1000);

  /* check if MODE SELECT button is pressed */
  do 
  {
    if(digitalRead(buttonPin1) == HIGH) 
      {
        /* wait until MODE SELECT button is released */
        do
          delay(20);
        while(digitalRead(buttonPin1) == HIGH);
        return;
      }
    delay(20);
  } while (true);

} /* End of MODEstandby */
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

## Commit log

2016-05-23 Revert "Version 1.0"
    This reverts commit 83d221ef146197ea9290c5dc10af98ee3c079f1e.
    [MIDIsonar.ino]
2016-06-18 Version 0.6
    Solved bug #1 'LDST and HDST displays wrong values when LDST>HDST and
    HDST<LDST' and solved bug #2 'Jitter at certain positions of the value
    dial'.
    [MIDIsonar.ino]
2016-06-26 Version 0.7
    Implemented play mode. Implemented is only sonar controller A. For this
    controller the complete functionality is implemented. Both controller
    types (MIDI notes and MIDI CC) are implemented.
2016-07-14 Version 0.8
    Solved bug #3 'Alternating adjacent notes when playing notes' and solved
    bug 'No NoteOff Midi message sent when hand is out of range'.
    [MIDIsonar.ino]
2016-07-15 version 0.9
    Implemented play mode for sonar controller B.
2017-03-06 Version 0.9 Corrected schematics
